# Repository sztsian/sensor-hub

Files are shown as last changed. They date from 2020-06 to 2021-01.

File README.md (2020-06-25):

# sensor-hub
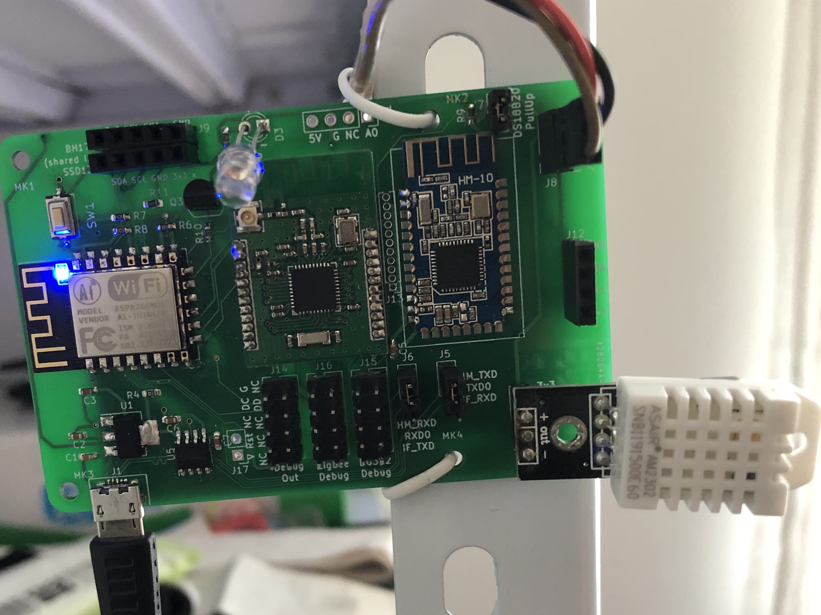
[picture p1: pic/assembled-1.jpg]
Assembled sensor hub board

This is an ESP8266 board with some connectors for sensors.

The board is made with Raspberry Pi 3 form factor so it can fit into a Raspberry Pi 3 B shell easily if you want.

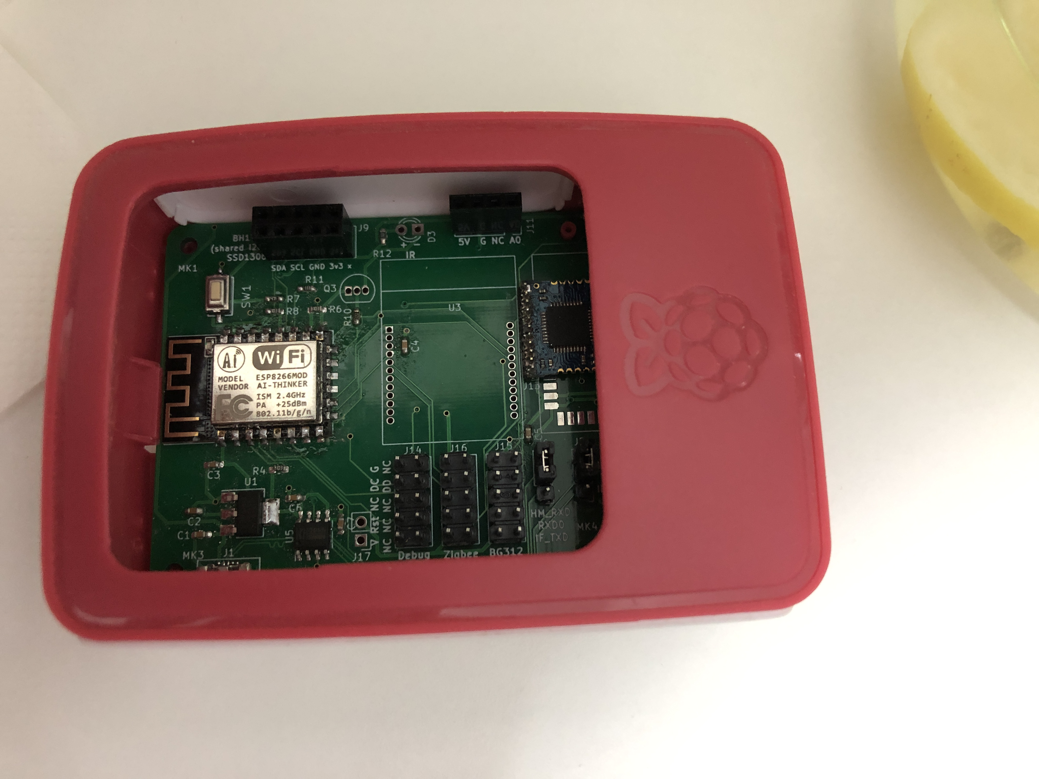
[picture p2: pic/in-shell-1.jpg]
Sensor hub board in a shell : top view

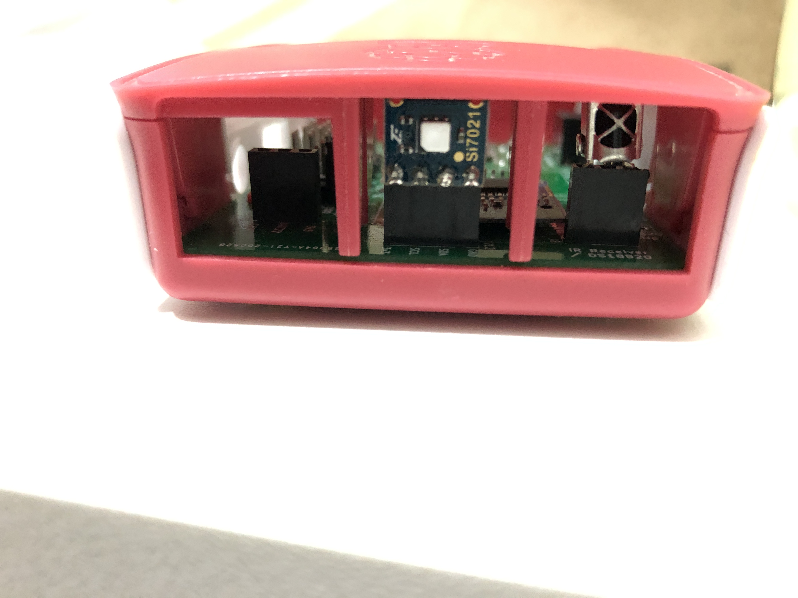
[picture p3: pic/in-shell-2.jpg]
Sensor hub board in a shell : side view


# Hardware

The board itself is design in KiCAD. Note, I am not a profession in electronics, so the board can be error pron or unstable.

The kicad symbol of the button is from [this website](http://smisioto.no-ip.org/elettronica/kicad/kicad-en.htm). You need to download the package/symbol and config it in your KiCAD.

# Firmware

[Tasmota](https://github.com/arendst/Tasmota) fits me well for gathering the sensor information and send it via MQTT. You can either download one from Tasmota, or compile your own for your need.
The config I use for [TasmoCompiler](https://github.com/benzino77/tasmocompiler) docker based compiler is available as `firmware/tasmota-zigbee-ir-i2c-user_config_override.h` .

The following is the config I use for the first picture.

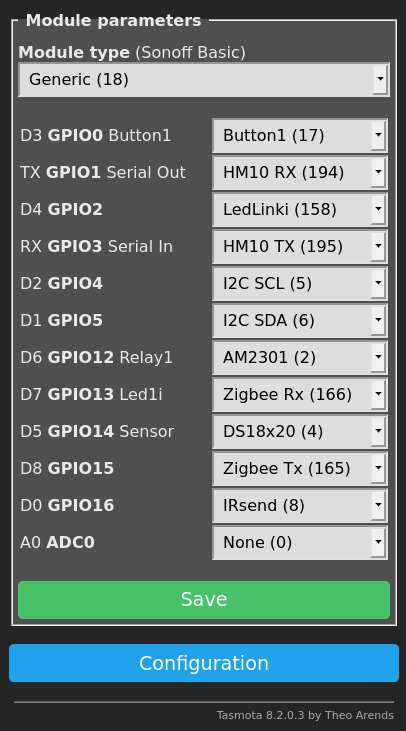
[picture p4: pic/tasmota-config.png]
Tasmota module config


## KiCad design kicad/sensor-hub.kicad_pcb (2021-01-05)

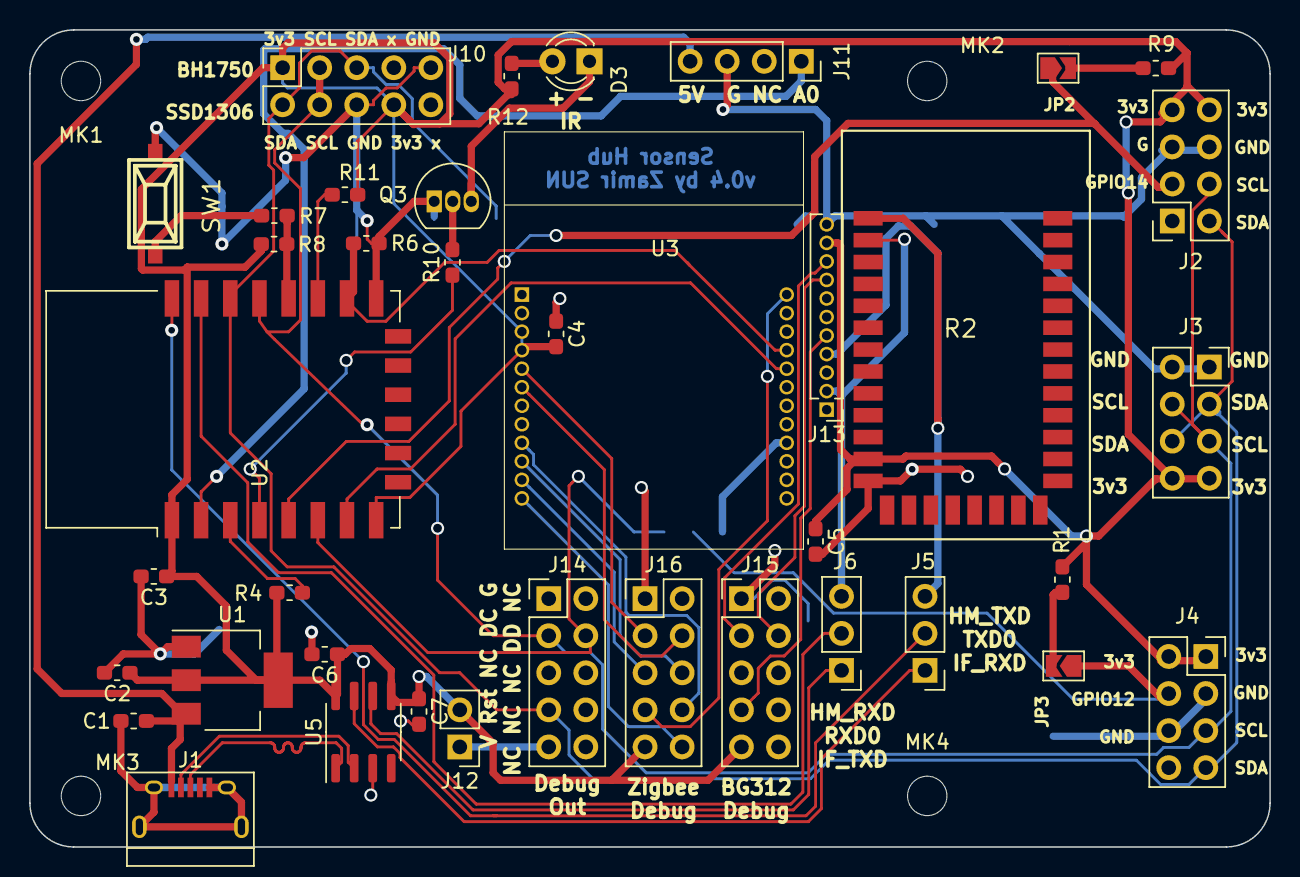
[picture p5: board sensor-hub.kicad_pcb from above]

Board: 2 copper layers, 85.0 x 56.0 mm, 44 parts (1 on the bottom side), 41 nets.

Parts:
C1: 10uF; C_0603_1608Metric_Pad1.05x0.95mm_HandSolder
C2: 100uF; C_0603_1608Metric_Pad1.05x0.95mm_HandSolder
C3, C4, C5, C6, C7: 100nF; C_0603_1608Metric_Pad1.05x0.95mm_HandSolder
D3: Infrared; LED_D3.0mm_IRBlack
J1: USB_B_Micro; USB_Micro-B_Connector
J2: IO14/SHT; PinSocket_2x04_P2.54mm_Vertical
J3: HDC/Si7021; PinSocket_2x04_P2.54mm_Vertical
J4: IO12/SHT; PinSocket_2x04_P2.54mm_Vertical
J5: ESP_TXD; PinHeader_1x03_P2.54mm_Vertical
J6: ESP_RXD; PinHeader_1x03_P2.54mm_Vertical
J10: BH1750/Display; PinSocket_2x05_P2.54mm_Vertical
J11: MQ_Sensors; PinSocket_1x04_P2.54mm_Vertical
J12: CC_PWR; PinHeader_1x02_P2.54mm_Vertical
J13: BG312L; PinHeader_1x11_P1.27mm_Vertical
J14: CC_DBG; PinHeader_2x05_P2.54mm_Vertical
J15: BT_DBG; PinHeader_2x05_P2.54mm_Vertical
J16: ZB_DBG; PinHeader_2x05_P2.54mm_Vertical
JP1: SJ_DHT; SolderJumper-3_P2.0mm_Open_TrianglePad1.0x1.5mm
JP2: SJ_GPIO14; SolderJumper-2_P1.3mm_Open_TrianglePad1.0x1.5mm
JP3: SJ_GPIO12; SolderJumper-2_P1.3mm_Open_TrianglePad1.0x1.5mm
MK1, MK2, MK3, MK4: M2.5; MountingHole_2.7mm_M2.5
Q3: PN2222A; TO-92_Inline
R1, R9: 4.7k; R_0603_1608Metric_Pad1.05x0.95mm_HandSolder
R2: hm10; HM10
R4, R6, R8: 10k; R_0603_1608Metric_Pad1.05x0.95mm_HandSolder
R7: 470; R_0603_1608Metric_Pad1.05x0.95mm_HandSolder
R10: 2.7k; R_0603_1608Metric_Pad1.05x0.95mm_HandSolder
R11: R_Small; R_0603_1608Metric_Pad1.05x0.95mm_HandSolder
R12: 2.5R; R_0603_1608Metric_Pad1.05x0.95mm_HandSolder
SW1: SW_Flash; smd_push
U1: AP1117-33; SOT-223-3_TabPin2
U2: ESP-12F; ESP-12E
U3: SZ1-CC2530
U5: CH330N; SOIC-8_3.9x4.9mm_P1.27mm

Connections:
3V3_MCU: C2.1, C3.1, C4.2, C5.1, C6.1, C7.1, J2.7, J2.8, J3.7, J3.8, J4.1, J4.2, J10.1, J10.8, J12.2, J13.10, J15.9, J16.9, R1.1, R2.12, R4.2, R8.1, R9.1, R11.1, R12.2, U1.2, U2.1, U2.8, U3.3, U3.4, U5.5, U5.8
/ZB_07: JP1.3, U3.16
/ZB_CLK: J16.6, U3.10
/ZB_CS: J16.5, U3.11
/ZB_DC: J16.3, U3.5
/ZB_DD: J16.4, U3.6
/ZB_MISO: J16.10, U3.12
/ZB_MOSI: J16.8, U3.9
/ZB_RST: J16.7, U3.24
A0: J11.1, U2.2
BT_DC: J13.9, J15.3
BT_DD: J13.8, J15.4
BT_RST: J13.5, J15.7
DHT22: J4.4, JP1.2, JP3.1
GND: C1.2, C2.2, C3.2, C4.1, C5.2, C6.2, C7.2, J1.5, J1.6, J2.5, J2.6, J3.1, J3.2, J4.3, J4.6, J10.6, J10.9, J11.3, J13.1, J13.11, J14.1, J15.1, J16.1, Q3.1, R2.13, R6.1, SW1.2, U1.1, U2.15, U3.1, U3.2, U5.3
GPIO0: R7.2, R8.2, U2.18
GPIO2: R11.2, U2.17
GPIO4: J2.4, J3.4, J3.5, J4.5, J10.3, J10.4, J14.3, U2.19
GPIO5: J2.2, J3.3, J3.6, J4.7, J10.2, J10.5, J14.7, U2.20
GPIO12: J14.4, JP1.1, U2.6
GPIO13: U2.7, U3.20
GPIO14: J2.3, JP2.1, U2.5
GPIO15: R6.2, U2.16, U3.21
GPIO16: R10.1, U2.4
HM_RXD: J6.3, J13.2, R2.2
HM_TXD: J5.3, J13.4, R2.1
IF_RXD: J5.1, U5.7
IF_TXD: J6.1, U5.6
IR_M: D3.1, Q3.3
IR_P: D3.2, R12.1
unnamed: J12.1, J14.9
unnamed: JP2.2, R9.2
unnamed: JP3.2, R1.2
unnamed: Q3.2, R10.2
unnamed: R4.1, U2.3
unnamed: R7.1, SW1.1
RXD0: J6.2, U2.21
TXD0: J5.2, U2.22
USB-D+: J1.3, U5.1
USB-D-: J1.2, U5.2
VBUS: C1.1, J1.1, J11.4, U1.3

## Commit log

2020-06-25 Initial sensor-hub kicad files
    [sensor-hub.kicad_pcb, sensor-hub.sch]
2020-06-25 Add cad libraries
2020-06-25 Update kicad files
    [sensor-hub.kicad_pcb]
2021-01-05 WIP: v0.4 with pin order converter board
    [sensor-hub.kicad_pcb, sensor-hub.sch]
2021-01-05 Finalize v0.4 version without pin converter board
    [sensor-hub.kicad_pcb, sensor-hub.sch]
